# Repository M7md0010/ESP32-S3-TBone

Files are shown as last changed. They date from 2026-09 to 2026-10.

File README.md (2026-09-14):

<p align="center">
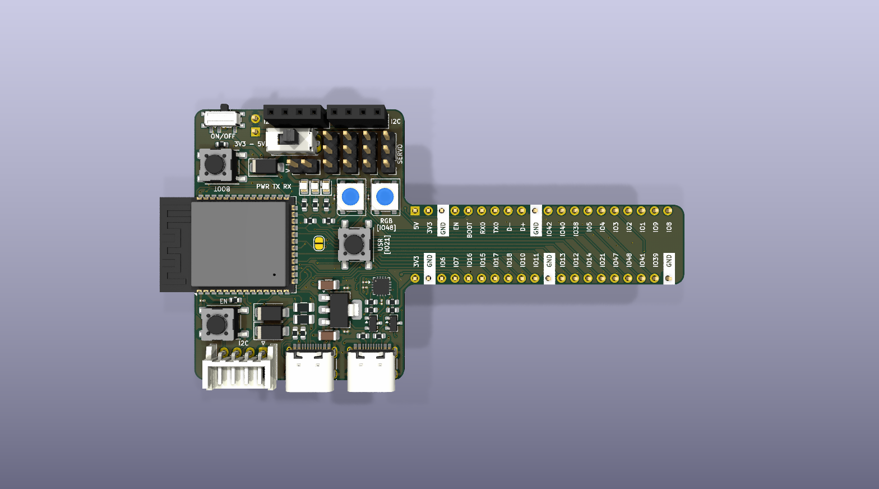
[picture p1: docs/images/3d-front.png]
ESP32-S3-TBone — Front 3D Render
  
</p>

<h1 align="center">ESP32-S3-TBone</h1>

<p align="center">
  <em>Custom T-bone form-factor ESP32-S3 development board engineered to resolve solderless breadboard real estate constraints by exposing dual-sided tie points.</em>
</p>

<p align="center">
  
  
  
  
</p>

---

## 📋 Project Overview

The **ESP32-S3-TBone** is a purpose-engineered development board built around the **ESP32-S3-WROOM-1** module. Unlike standard rectangular devkits that monopolize the entire breadboard, the T-bone form factor features a narrowed neck section that straddles the center channel while the head section extends beyond the breadboard edge — freeing up **both sides** of the breadboard for prototyping access to all GPIO tie points.

### Key Design Goals

- **Maximize breadboard usable area** — dual-sided tie point access for all broken-out GPIOs.
- **Signal integrity first** — 4-layer controlled-impedance stackup with dedicated ground and power reference planes.
- **Manufacturing ready** — Gerber-optimized output with DFM rule compliance for standard PCB fabs (JLCPCB, PCBWay, Norisolutions).
- **Mechanical validation** — 3D collision-checked against standard 830-point breadboard models in Fusion 360.

---

## 🏗️ Hardware Architecture & Stackup

### MCU: ESP32-S3-WROOM-1

| Parameter | Specification |
| --- | --- |
| Core | Xtensa® dual-core 32-bit LX7 |
| Clock | Up to 240 MHz |
| Flash | 16 MB (Quad SPI) |
| SRAM | 512 KB |
| Connectivity | Wi-Fi 802.11 b/g/n + Bluetooth 5 (LE)  |
| USB | Native USB 2.0 OTG + UART via CH343P |
| GPIO | Fully broken-out via dual header rows |

### Onboard Hardware Features & Peripherals

- **I2C Interface:** Dedicated extracted socket/pins for fast and reliable I2C peripheral expansion.
- **Servo Motor Headers:** Onboard header pins specifically broken out for direct servo motor control.
- **Addressable RGB LEDs:** 2× onboard WS2812B RGB LEDs for customizable status indication and visual feedback.
- **Flexible Power Inputs:** Power the board via either of the USB Type-C ports or directly through the header pins.
- **Switchable Breadboard Power Rails:** Two mechanically fit pins designed to drop directly into the breadboard's power rails. Features a dedicated toggle switch to select between **3.3V** and **5V** logic levels for the breadboard.
- **Main Power Switch:** Dedicated ON/OFF toggle switch for main board power.
- **Programmable User Button:** A custom tactile push button hooked up with a pull resistor, ready to be programmed for user input.
- **PTC Thermistors:** Onboard resettable fuses for robust overcurrent protection.

### 4-Layer PCB Stackup

```
┌─────────────────────────────────────────────────────────┐
│  Layer 1 — F.Cu (Top)                                   │
│  → High-density signal routing, component pads,         │
│    USB differential pairs, crystal oscillator traces     │
├─────────────────────────────────────────────────────────┤
│  Layer 2 — In1.Cu (Inner 1)                             │
│  → Solid continuous ground (GND) reference plane        │
│    Provides low-impedance return path for all signals   │
├─────────────────────────────────────────────────────────┤
│  Layer 3 — In2.Cu (Inner 2)                             │
│  → Partitioned low-impedance power planes               │
│    • 3V3 polygon pour — main logic supply               │
│    • 5V rail — USB VBUS passthrough                     │
│    • VBUS — upstream USB input power                    │
├─────────────────────────────────────────────────────────┤
│  Layer 4 — B.Cu (Bottom)                                │
│  → Bottom interconnects, ground return stitching,       │
│    thermal relief pads, and auxiliary signal routing     │
└─────────────────────────────────────────────────────────┘
```

---

## 🔧 Design For Manufacturability (DFM) & Layout

### EMI Shielding — Perimeter Via Stitching
A continuous array of stitching vias along the board perimeter connects the top and bottom ground pours, forming a **Faraday cage** effect. This:
- Contains return currents within the board stackup
- Reduces edge-radiated EMI emissions
- Improves ground plane continuity at board boundaries

### Neck Corner Geometry — CNC Routing Clearance
The interior corners at the T-bone neck-to-head transition use **chamfered/radiused fillets** to accommodate standard CNC routing bit diameters (≥ 0.8 mm). Sharp 90° interior corners are physically impossible to mill and would cause fabrication rejects.

### Soldermask-Clipped Silkscreen
The `--subtract-soldermask` flag was used during Gerber generation to automatically **clip silkscreen artwork** wherever it overlaps exposed copper pads. This prevents:
- Ink-on-pad contamination during soldering
- Poor solder wetting on component pads
- IPC-A-610 Class 2/3 violations

### USB Type-C CC Pull-Down Logic
Both USB-C ports implement the correct **CC1/CC2 pull-down resistor** network (5.1 kΩ to GND) on each Configuration Channel pin, advertising the device as a **UFP (Upstream Facing Port)** sink per USB Type-C spec Rev 2.0. This ensures reliable cable detection and power negotiation with all USB-C hosts and chargers.

---

## 🧊 Mechanical Validation

The board outline (exported as `.step` from KiCad) was imported into **Autodesk Fusion 360** alongside a reference breadboard CAD model to perform:

1. **Collision detection** — verify zero interference between the PCB body and breadboard clips/housing.
2. **Tie-point clearance** — confirm all header pins align with breadboard hole pitch (2.54 mm / 0.1").
3. **Overhang validation** — ensure the head section clears the breadboard edge without cantilever instability.

<p align="center">
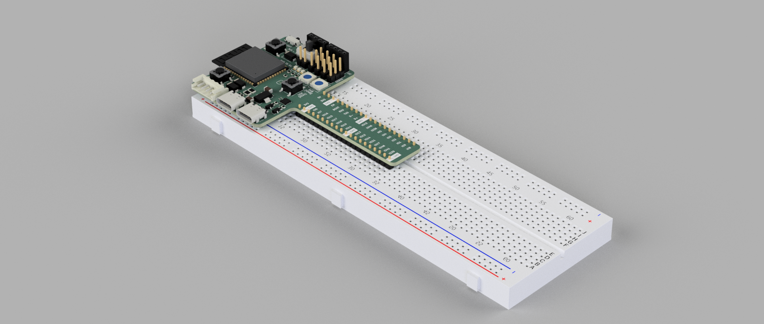
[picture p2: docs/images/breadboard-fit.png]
Breadboard fit verification
  
</p>

---

## 📸 Gallery

| Front (3D Render) | Back (3D Render) |
|---|---|
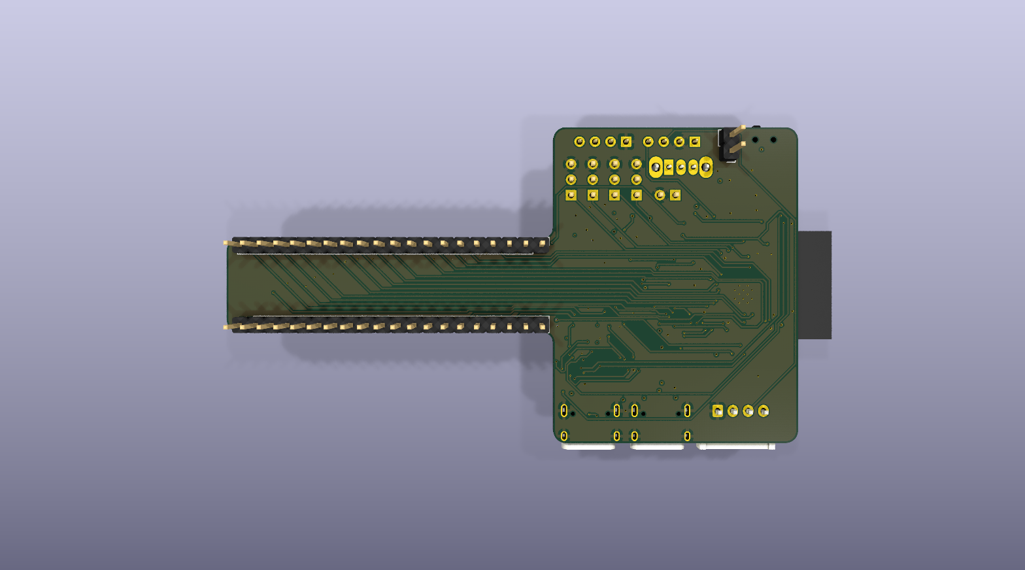
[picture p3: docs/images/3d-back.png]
Back
| Front |  |

| Front (No Components) | Back (No Components) |
|---|---|
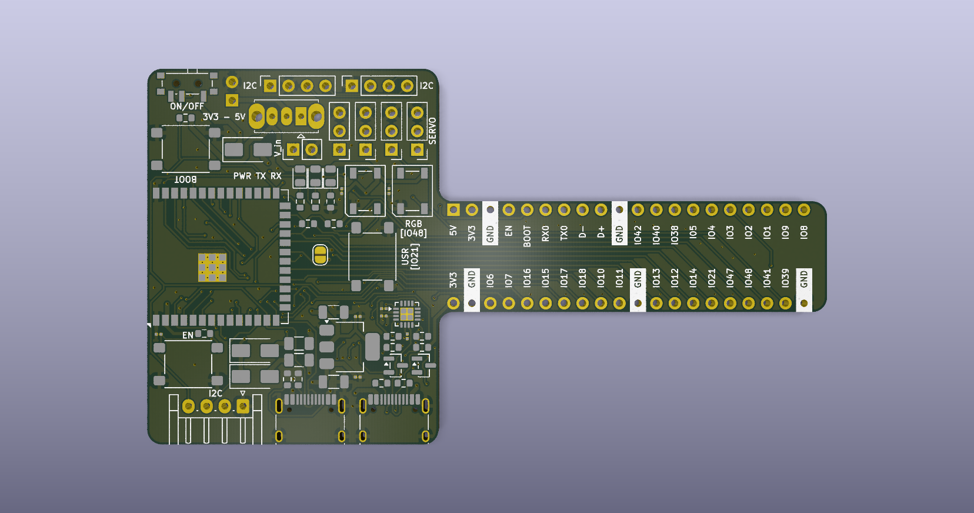
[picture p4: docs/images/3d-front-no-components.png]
Front NC
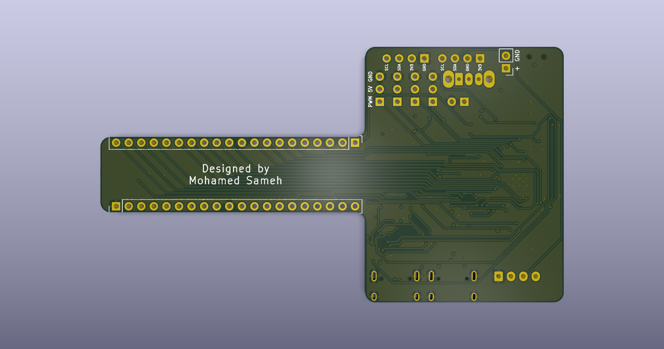
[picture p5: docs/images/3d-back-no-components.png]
Back NC
|  |  |

---

## 📁 Directory Structure

```
ESP32-S3-TBone/
├── hardware/
│   ├── schematics/
│   │   ├── schematic.pdf            # Exported schematic drawing (PDF)
│   │   └── v1.0.kicad_sch           # KiCad schematic source
│   ├── pcb/
│   │   ├── v1.0.kicad_pcb           # KiCad PCB layout source
│   │   ├── v1.0.kicad_pro           # KiCad project file
│   │   └── v1.0.kicad_dru           # KiCad design rules
│   ├── gerbers/
│   │   ├── gerbers.zip              # Production-ready Gerber + Drill archive
│   │   ├── v1.0-F_Cu.gtl            # Front copper
│   │   ├── v1.0-In1_Cu.g1           # Inner layer 1 (GND plane)
│   │   ├── v1.0-In2_Cu.g2           # Inner layer 2 (Power planes)
│   │   ├── v1.0-B_Cu.gbl            # Back copper
│   │   ├── v1.0-F_Mask.gts          # Front solder mask
│   │   ├── v1.0-B_Mask.gbs          # Back solder mask
│   │   ├── v1.0-F_Silkscreen.gto    # Front silkscreen
│   │   ├── v1.0-B_Silkscreen.gbo    # Back silkscreen
│   │   ├── v1.0-Edge_Cuts.gm1       # Board outline
│   │   ├── v1.0.drl                 # Excellon drill file
│   │   ├── v1.0-drl_map.gbr         # Drill map (Gerber X2)
│   │   └── ...                      # Additional fabrication layers
│   └── mechanical/
│       ├── ESP32-S3-TBone.step       # 3D STEP assembly export
│       ├── Breadboard.fbx            # Breadboard reference model
│       └── breadboard-reference.glb  # Breadboard GLB model
├── docs/
│   └── images/
│       ├── 3d-front.png              # Front 3D render
│       ├── 3d-back.png               # Back 3D render
│       ├── 3d-front-no-components.png
│       ├── 3d-back-no-components.png
│       ├── breadboard-fit.png        # Breadboard fit verification
│       └── comparison.png            # Size comparison
├── .gitignore
├── LICENSE                            # MIT License
└── README.md                          # This file
```

---

## 🛠️ Regenerating Manufacturing Files

If you modify the KiCad source files, regenerate all outputs using `kicad-cli`:

```bash
# Gerber layers (with soldermask-clipped silkscreen)
kicad-cli pcb export gerbers --subtract-soldermask \
  -o hardware/gerbers/ hardware/pcb/v1.0.kicad_pcb

# Excellon drill files + Gerber X2 drill map
kicad-cli pcb export drill --generate-map --map-format gerberx2 \
  -o hardware/gerbers/ hardware/pcb/v1.0.kicad_pcb

# Schematic PDF
kicad-cli sch export pdf \
  -o hardware/schematics/schematic.pdf hardware/schematics/v1.0.kicad_sch

# STEP 3D assembly (skip DNP, substitute models)
kicad-cli pcb export step --no-dnp --subst-models \
  -o hardware/mechanical/ESP32-S3-TBone.step hardware/pcb/v1.0.kicad_pcb
```

---

## 📜 License

This project is licensed under the **MIT License** — see the [LICENSE](./LICENSE) file for details.

---

<p align="center">
  <sub>Designed & engineered by <a href="https://github.com/M7md0010">@M7md0010</a></sub>
</p>

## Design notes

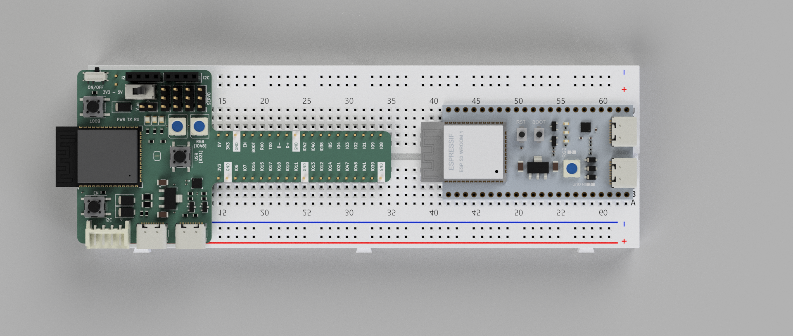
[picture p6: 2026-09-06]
docs/images/comparison.png

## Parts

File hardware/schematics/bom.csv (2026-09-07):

Refs | Value | Footprint | Qty | DNP
C1 | 100 nF | Capacitor_SMD:C_0201_0603Metric | 1
C2 | 100 nF | Capacitor_SMD:C_0201_0603Metric | 1
C3 | 100 nF | Capacitor_SMD:C_0201_0603Metric | 1
C4 | 100 nF | Capacitor_SMD:C_0201_0603Metric | 1
C5 | 100 nF | Capacitor_SMD:C_0201_0603Metric | 1
C6 | 100 nF | Capacitor_SMD:C_0201_0603Metric | 1
C7 | 22μF | Capacitor_SMD:C_1206_3216Metric | 1
C8 | 100nF | Capacitor_SMD:C_0201_0603Metric | 1
C9 | 100nF | Capacitor_SMD:C_0201_0603Metric | 1
C10 | 22μF | Capacitor_SMD:C_1206_3216Metric | 1
D1 | SS34 | Diode_SMD:D_SMA | 1
D2 | SS34 | Diode_SMD:D_SMA | 1
D3 | SS34 | Diode_SMD:D_SMA | 1
D6 | LED | LED_SMD:LED_0805_2012Metric | 1
D7 | LED | LED_SMD:LED_0805_2012Metric | 1
D8 | LED | LED_SMD:LED_0805_2012Metric | 1
D9 | WS2812B | LED_SMD:LED_WS2812B_PLCC4_5.0x5.0mm_P3.2mm | 1
D10 | WS2812B | LED_SMD:LED_WS2812B_PLCC4_5.0x5.0mm_P3.2mm | 1
J1 | Conn_01x04_Pin | Connector_PinSocket_2.54mm:PinSocket_1x04_P2.54mm_Vertical | 1
J2 | Conn_01x04_Pin | Connector_PinSocket_2.54mm:PinSocket_1x04_P2.54mm_Vertical | 1
J3 | Conn_01x03_Pin | Connector_PinHeader_2.54mm:PinHeader_1x03_P2.54mm_Vertical | 1
J4 | Conn_01x03_Pin | Connector_PinHeader_2.54mm:PinHeader_1x03_P2.54mm_Vertical | 1
J5 | Conn_01x03_Pin | Connector_PinHeader_2.54mm:PinHeader_1x03_P2.54mm_Vertical | 1
J6 | Conn_01x03_Pin | Connector_PinHeader_2.54mm:PinHeader_1x03_P2.54mm_Vertical | 1
J7 | USB_C_Receptacle_USB2.0_14P | Connector_USB:USB_C_Receptacle_HRO_TYPE-C-31-M-12 | 1
J8 | Conn_01x20_Pin | Connector_PinHeader_2.54mm:PinHeader_1x20_P2.54mm_Vertical | 1
J9 | Conn_01x20_Pin | Connector_PinHeader_2.54mm:PinHeader_1x20_P2.54mm_Vertical | 1
J10 | Conn_01x04_Socket | Connector_JST:JST_EH_S4B-EH_1x04_P2.50mm_Horizontal | 1
J11 | USB_C_Receptacle_USB2.0_14P | Connector_USB:USB_C_Receptacle_HRO_TYPE-C-31-M-12 | 1
J14 | Conn_01x02_Pin | Connector_PinHeader_2.54mm:PinHeader_1x02_P2.54mm_Vertical | 1
J15 | Conn_01x02_Pin | Connector_PinHeader_2.54mm:PinHeader_1x02_P2.54mm_Vertical | 1
JP2 | Jumper_2_Open | Jumper:SolderJumper-2_P1.3mm_Open_RoundedPad1.0x1.5mm | 1
Q1 | MMBT3904 | Package_TO_SOT_SMD:SOT-23 | 1
Q2 | MMBT3904 | Package_TO_SOT_SMD:SOT-23 | 1
R1 | 5.1kΩ | Resistor_SMD:R_0603_1608Metric | 1
R2 | 5.1kΩ | Resistor_SMD:R_0603_1608Metric | 1
R3 | 10kΩ | Resistor_SMD:R_0603_1608Metric | 1
R4 | 10kΩ | Resistor_SMD:R_0603_1608Metric | 1
R5 | 10kΩ | Resistor_SMD:R_0603_1608Metric | 1
R6 | 5.1kΩ | Resistor_SMD:R_0603_1608Metric | 1
R7 | 5.1kΩ | Resistor_SMD:R_0603_1608Metric | 1
R8 | 10kΩ | Resistor_SMD:R_0603_1608Metric | 1
R9 | 10kΩ | Resistor_SMD:R_0603_1608Metric | 1
R10 | 10kΩ | Resistor_SMD:R_0603_1608Metric | 1
R11 | 10kΩ | Resistor_SMD:R_0603_1608Metric | 1
R12 | 330Ω | Resistor_SMD:R_0603_1608Metric | 1
R13 | 1kΩ | Resistor_SMD:R_0603_1608Metric | 1
R14 | 1kΩ | Resistor_SMD:R_0603_1608Metric | 1
R15 | 1kΩ | Resistor_SMD:R_0603_1608Metric | 1
SW1 | SW_Push | Button_Switch_SMD:SW_SPST_PTS645Sx43SMTR92 | 1
SW2 | SW_Push | Button_Switch_SMD:SW_SPST_PTS645Sx43SMTR92 | 1
SW3 | SW_Push | Button_Switch_SMD:SW_SPST_PTS645Sx43SMTR92 | 1
SW4 | SW_SPDT | Button_Switch_SMD:SW_SPDT_PCM12 | 1
SW5 | SW_SPDT | Button_Switch_THT:SW_Slide_SPDT_Straight_CK_OS102011MS2Q | 1
TH1 | Thermistor_PTC | Fuse:Fuse_1206_3216Metric | 1
TH2 | Thermistor_PTC | Fuse:Fuse_1206_3216Metric | 1
U1 | CH343P | Package_DFN_QFN:WCH_QFN-16-1EP_3x3mm_P0.5mm_EP1.8x1.8mm | 1
U2 | ESP32-S3-WROOM-1 | RF_Module:ESP32-S3-WROOM-1 | 1
U3 | AMS1117-3.3 | Package_TO_SOT_SMD:SOT-223-3_TabPin2 | 1

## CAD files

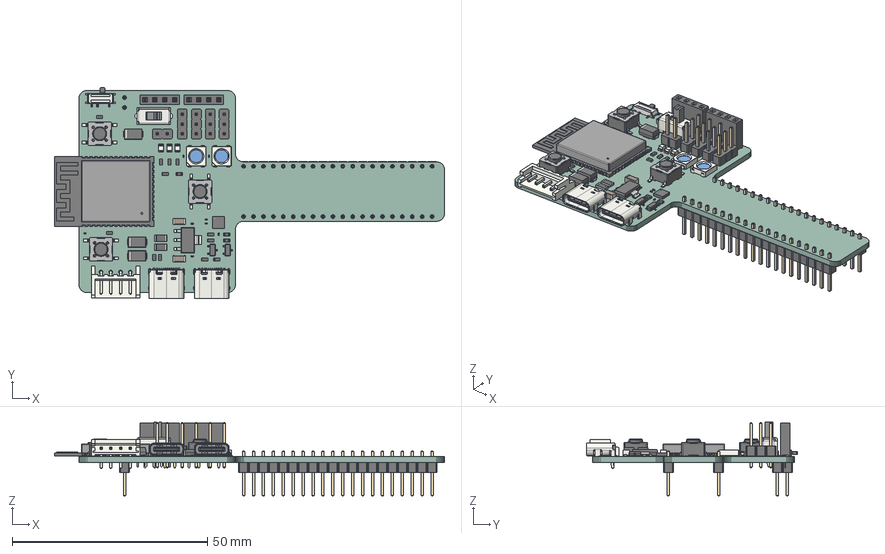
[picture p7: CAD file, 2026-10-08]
hardware/mechanical/v1.0.step
99.8 x 54.0 x 18.9 mm
R_0603_1608Metric x 15
Fusion_sp
LED_WS2812B_PLCC4_50x50mm_P32mm x 2
C_0201_0603Metric x 8
LED_0805_2012Metric x 3
SW_Slide_SPDT_Straight_CK_OS102011MS2Q
SW_SPST_PTS645Sx43SMTR92 x 3
USB_C_Receptacle_16P_TopMnt_Horizontal_GCT_USB4105-xx-A x 2
PinHeader_1x02_P254mm_Vertical x 2
PinHeader_1x03_P254mm_Vertical x 4
SOT-223
D_SMA x 3
SOT-23 x 2
QFN-16-1EP_3x3mm_P0.5mm_EP1.7x1.7mm
C_1206_3216Metric x 2
PinSocket_1x04_P2.54mm_Vertical x 2
JST_S4B_EH
Fuse_1206_3216Metric x 2
ESP32-S3-WROOM-1
PinHeader_1x20_P254mm_Vertical x 2
v1.0_PCB

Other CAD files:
hardware/mechanical/ESP32-S3-TBone.step

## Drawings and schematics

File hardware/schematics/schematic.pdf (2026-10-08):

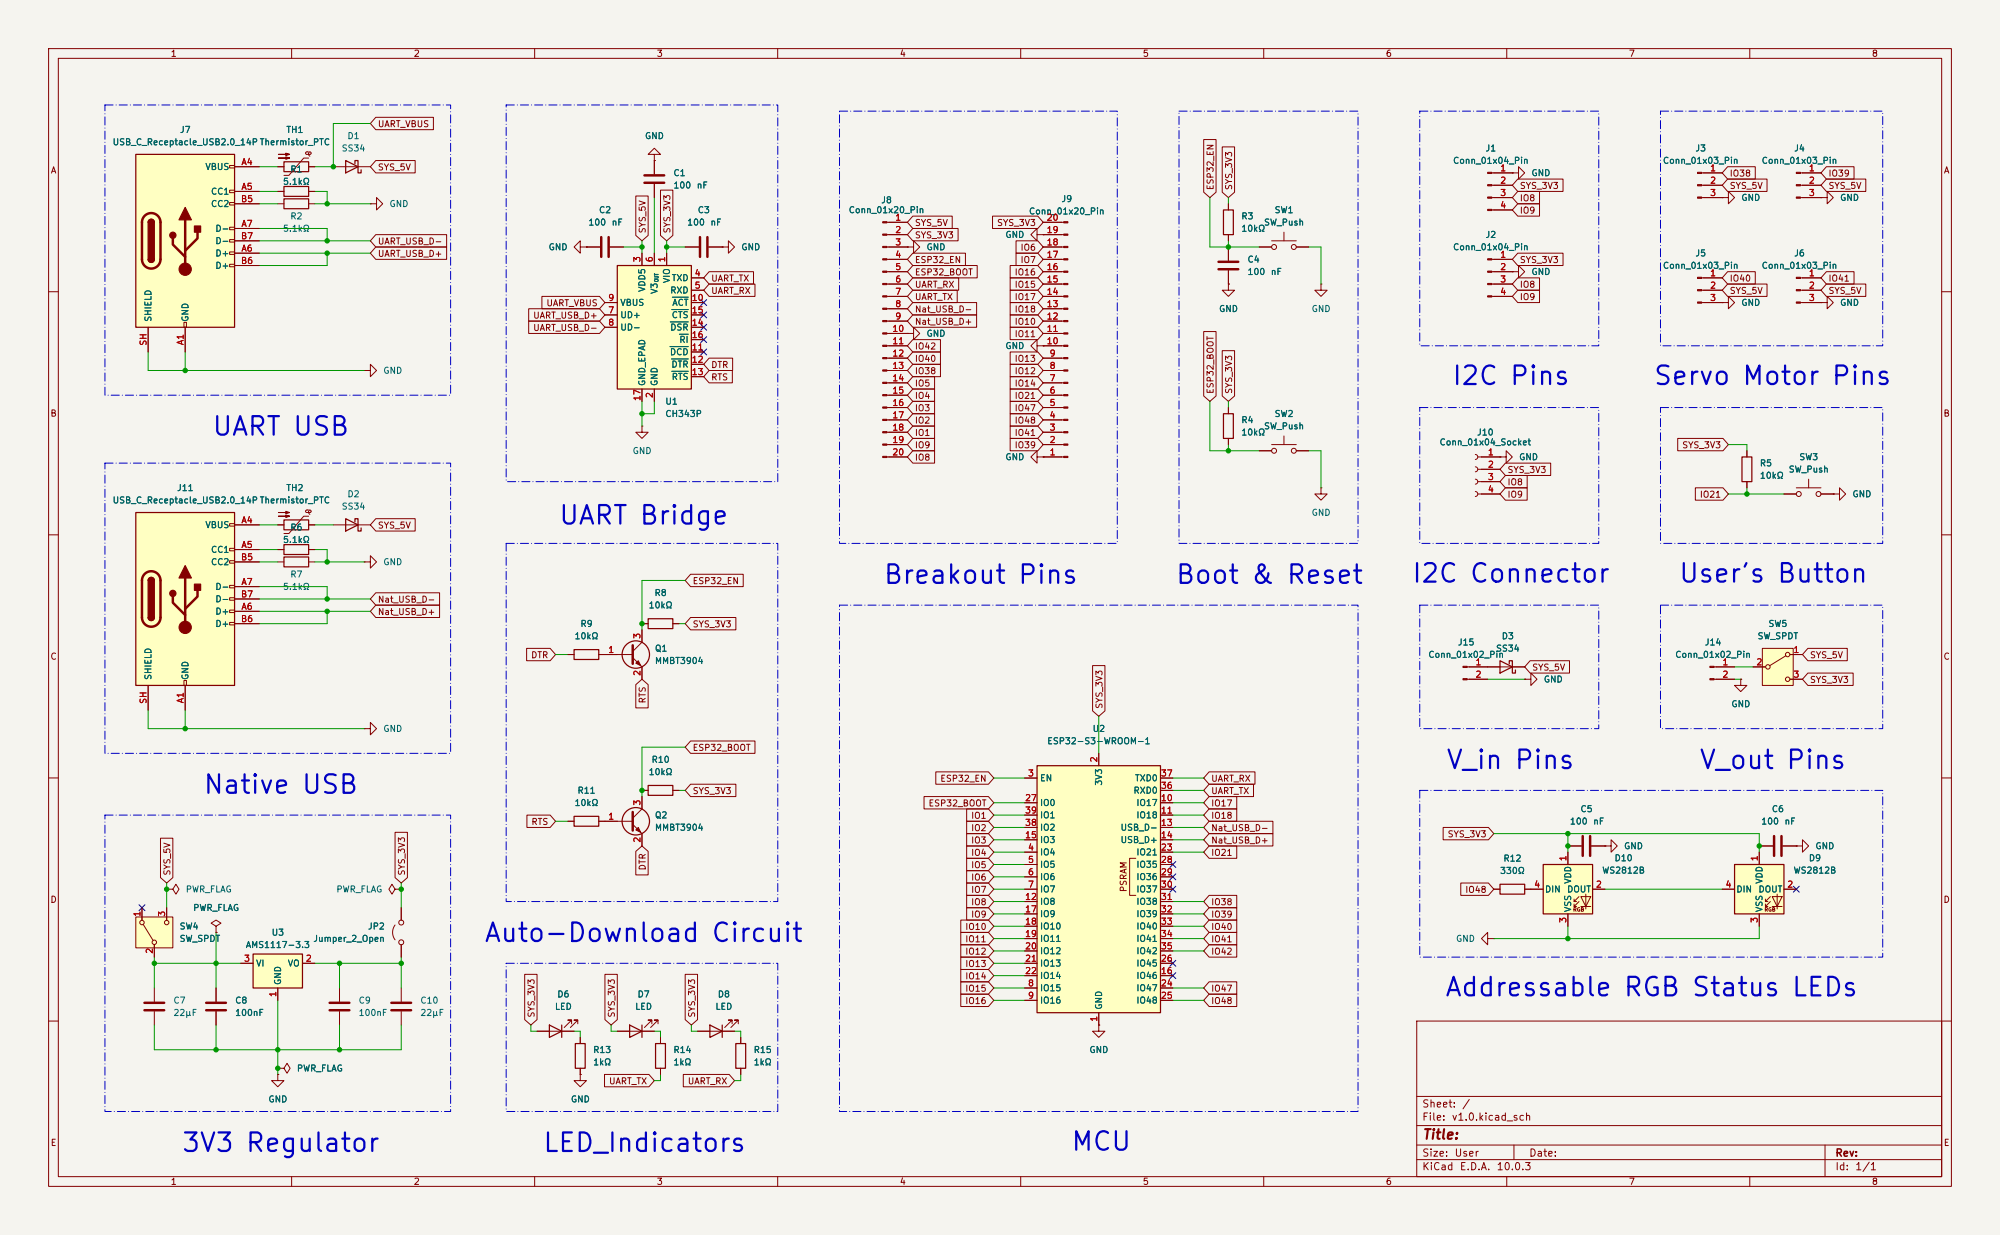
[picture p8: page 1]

ACT 10 DCD 11 DTR 12 RTS 13 DSR 14 CTS 15 RI 16 C2

1 VDD5
ACT 10 DCD 11 DTR 12 RTS 13 DSR 14 CTS 15 RI 16 U1CH343P

GND
Addressable RGB Status LEDs

Size: User | Rev:
KiCad E.D.A. 10.0.3 | Id: 1/1

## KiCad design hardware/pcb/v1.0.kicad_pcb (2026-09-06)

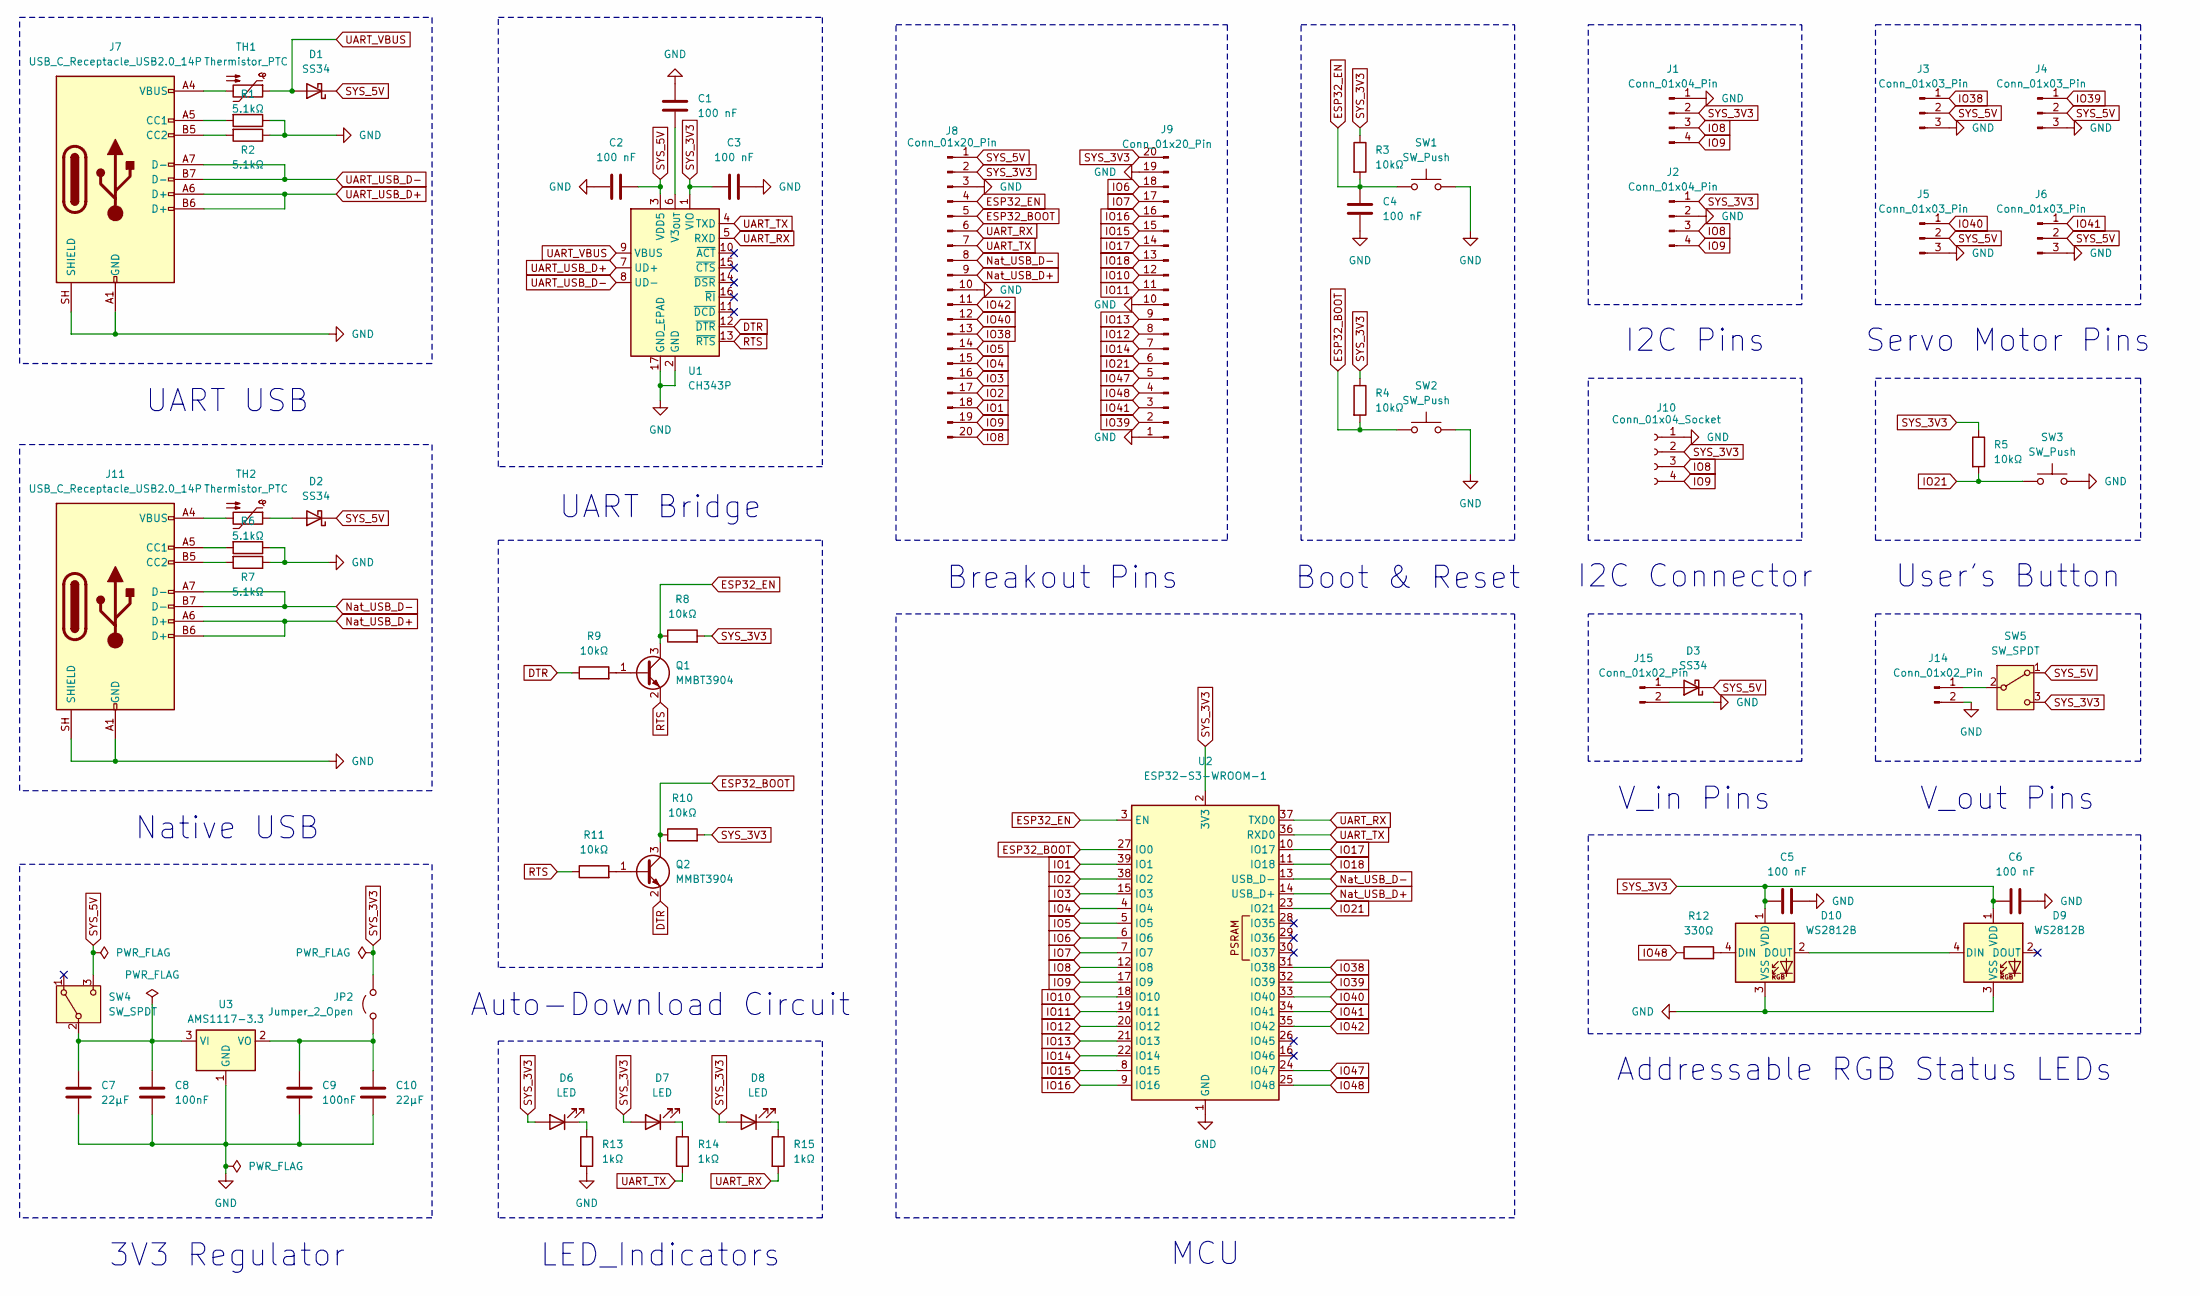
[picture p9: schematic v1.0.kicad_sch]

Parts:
C1, C2, C3, C4, C5, C6: 100 nF; C_0201_0603Metric
C7, C10: 22μF; C_1206_3216Metric
C8, C9: 100nF; C_0201_0603Metric
D1, D2, D3: SS34; D_SMA
D6, D7, D8: LED; LED_0805_2012Metric
D9, D10: WS2812B; LED_WS2812B_PLCC4_5.0x5.0mm_P3.2mm
J1, J2: Conn_01x04_Pin; PinSocket_1x04_P2.54mm_Vertical
J3, J4, J5, J6: Conn_01x03_Pin; PinHeader_1x03_P2.54mm_Vertical
J7, J11: USB_C_Receptacle_USB2.0_14P; USB_C_Receptacle_HRO_TYPE-C-31-M-12
J8, J9: Conn_01x20_Pin; PinHeader_1x20_P2.54mm_Vertical
J10: Conn_01x04_Socket; JST_EH_S4B-EH_1x04_P2.50mm_Horizontal
J14, J15: Conn_01x02_Pin; PinHeader_1x02_P2.54mm_Vertical
JP2: Jumper_2_Open; SolderJumper-2_P1.3mm_Open_RoundedPad1.0x1.5mm
Q1, Q2: MMBT3904; SOT-23
R1, R2, R6, R7: 5.1kΩ; R_0603_1608Metric
R3, R4, R5, R8, R9, R10, R11: 10kΩ; R_0603_1608Metric
R12: 330Ω; R_0603_1608Metric
R13, R14, R15: 1kΩ; R_0603_1608Metric
SW1, SW2, SW3: SW_Push; SW_SPST_PTS645Sx43SMTR92
SW4: SW_SPDT; SW_SPDT_PCM12
SW5: SW_SPDT; SW_Slide_SPDT_Straight_CK_OS102011MS2Q
TH1, TH2: Thermistor_PTC; Fuse_1206_3216Metric
U1: CH343P; WCH_QFN-16-1EP_3x3mm_P0.5mm_EP1.8x1.8mm
U2: ESP32-S3-WROOM-1
U3: AMS1117-3.3; SOT-223-3_TabPin2

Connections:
DTR: Q2.2 (E), R9.1, U1.12 (~DTR)
ESP32_BOOT: J8.5, Q2.3 (C), R4.2, R10.1, SW2.1, U2.27 (IO0)
ESP32_EN: C4.1, J8.4, Q1.3 (C), R3.2, R8.1, SW1.1, U2.3 (EN)
GND: C1.1, C2.2, C3.1, C4.2, C5.1, C6.1, C7.2, C8.2, C9.2, C10.2, D9.3 (VSS), D10.3 (VSS), J1.1, J2.2, J3.3, J4.3, J5.3, J6.3, J7.A1 (GND), J7.A12 (GND), J7.B1 (GND), J7.B12 (GND), J7.SH (SHIELD), J8.3, J8.10, J9.1, J9.10, J9.19, J10.1, J11.A1 (GND), J11.A12 (GND), J11.B1 (GND), J11.B12 (GND), J11.SH (SHIELD), J14.2, J15.2, R1.1, R2.1, R6.1, R7.1, R13.2, SW1.2, SW2.2, SW3.2, U1.2 (GND), U1.17 (GND_EPAD), U2.1 (GND), U2.40 (GND), U2.41 (GND), U3.1 (GND)
IO1: J8.18, U2.39 (IO1)
IO2: J8.17, U2.38 (IO2)
IO3: J8.16, U2.15 (IO3)
IO4: J8.15, U2.4 (IO4)
IO5: J8.14, U2.5 (IO5)
IO6: J9.18, U2.6 (IO6)
IO7: J9.17, U2.7 (IO7)
IO8: J1.3, J2.3, J8.20, J10.3, U2.12 (IO8)
IO9: J1.4, J2.4, J8.19, J10.4, U2.17 (IO9)
IO10: J9.12, U2.18 (IO10)
IO11: J9.11, U2.19 (IO11)
IO12: J9.8, U2.20 (IO12)
IO13: J9.9, U2.21 (IO13)
IO14: J9.7, U2.22 (IO14)
IO15: J9.15, U2.8 (IO15)
IO16: J9.16, U2.9 (IO16)
IO17: J9.14, U2.10 (IO17)
IO18: J9.13, U2.11 (IO18)
IO21: J9.6, R5.2, SW3.1, U2.23 (IO21)
IO38: J3.1, J8.13, U2.31 (IO38)
IO39: J4.1, J9.2, U2.32 (IO39)
IO40: J5.1, J8.12, U2.33 (IO40)
IO41: J6.1, J9.3, U2.34 (IO41)
IO42: J8.11, U2.35 (IO42)
IO47: J9.5, U2.24 (IO47)
IO48: J9.4, R12.1, U2.25 (IO48)
Nat_USB_D+: J8.9, J11.A6 (D+), J11.B6 (D+), U2.14 (USB_D+)
Nat_USB_D-: J8.8, J11.A7 (D-), J11.B7 (D-), U2.13 (USB_D-)
unnamed: D2.2 (A), TH2.1
unnamed: D3.2 (A), J15.1
unnamed: D6.1 (K), R13.1
unnamed: D7.1 (K), R14.1
unnamed: D8.1 (K), R15.1
unnamed: D10.4 (DIN), R12.2
unnamed: D9.4 (DIN), D10.2 (DOUT)
unnamed: J7.A5 (CC1), R1.2
unnamed: J7.B5 (CC2), R2.2
unnamed: J7.A4 (VBUS), J7.A9 (VBUS), J7.B4 (VBUS), J7.B9 (VBUS), TH1.2
unnamed: J11.A5 (CC1), R6.2
unnamed: J11.B5 (CC2), R7.2
unnamed: J11.A4 (VBUS), J11.A9 (VBUS), J11.B4 (VBUS), J11.B9 (VBUS), TH2.2
unnamed: J14.1, SW5.2 (B)
unnamed: C9.1, C10.1, JP2.1 (A), U3.2 (VO)
unnamed: Q1.1 (B), R9.2
unnamed: Q2.1 (B), R11.2
unnamed: C7.1, C8.1, SW4.2 (B), U3.3 (VI)
unnamed: C1.2, U1.6 (V3_{OUT})
RTS: Q1.2 (E), R11.1, U1.13 (~RTS)
SYS_3V3: C3.2, C5.2, C6.2, D6.2 (A), D7.2 (A), D8.2 (A), D9.1 (VDD), D10.1 (VDD), J1.2, J2.1, J8.2, J9.20, J10.2, JP2.2 (B), R3.1, R4.1, R5.1, R8.2, R10.2, SW5.3 (C), U1.1 (VIO), U2.2 (3V3)
SYS_5V: C2.1, D1.1 (K), D2.1 (K), D3.1 (K), J3.2, J4.2, J5.2, J6.2, J8.1, SW4.3 (C), SW5.1 (A), U1.3 (VDD5)
UART_RX: J8.6, R15.2, U1.5 (RXD), U2.37 (TXD0)
UART_TX: J8.7, R14.2, U1.4 (TXD), U2.36 (RXD0)
UART_USB_D+: J7.A6 (D+), J7.B6 (D+), U1.7 (UD+)
UART_USB_D-: J7.A7 (D-), J7.B7 (D-), U1.8 (UD-)
UART_VBUS: D1.2 (A), TH1.1, U1.9 (VBUS)

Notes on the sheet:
Servo Motor Pins
Auto-Download Circuit
UART USB
MCU
LED_Indicators
3V3 Regulator
Boot & Reset
Breakout Pins
UART Bridge
Native USB
User's Button
I2C Connector
V_in Pins
I2C Pins
Addressable RGB Status LEDs
V_out Pins

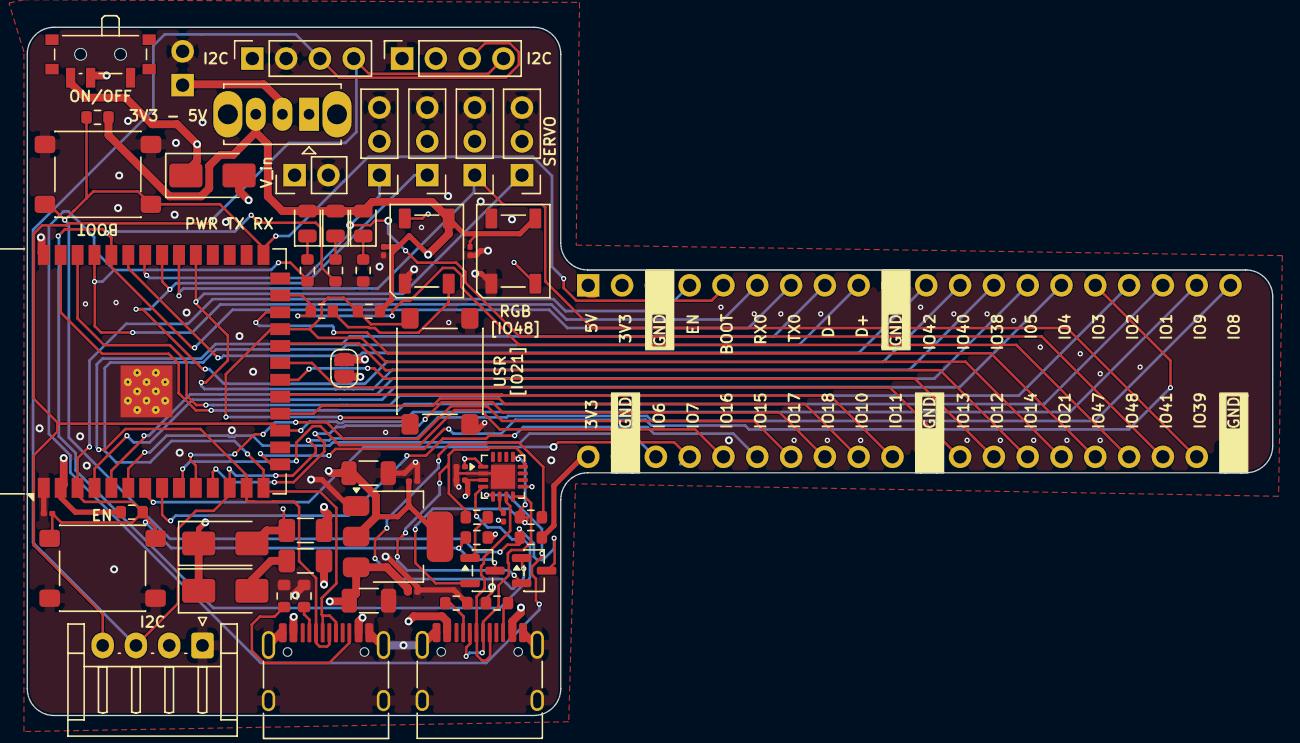
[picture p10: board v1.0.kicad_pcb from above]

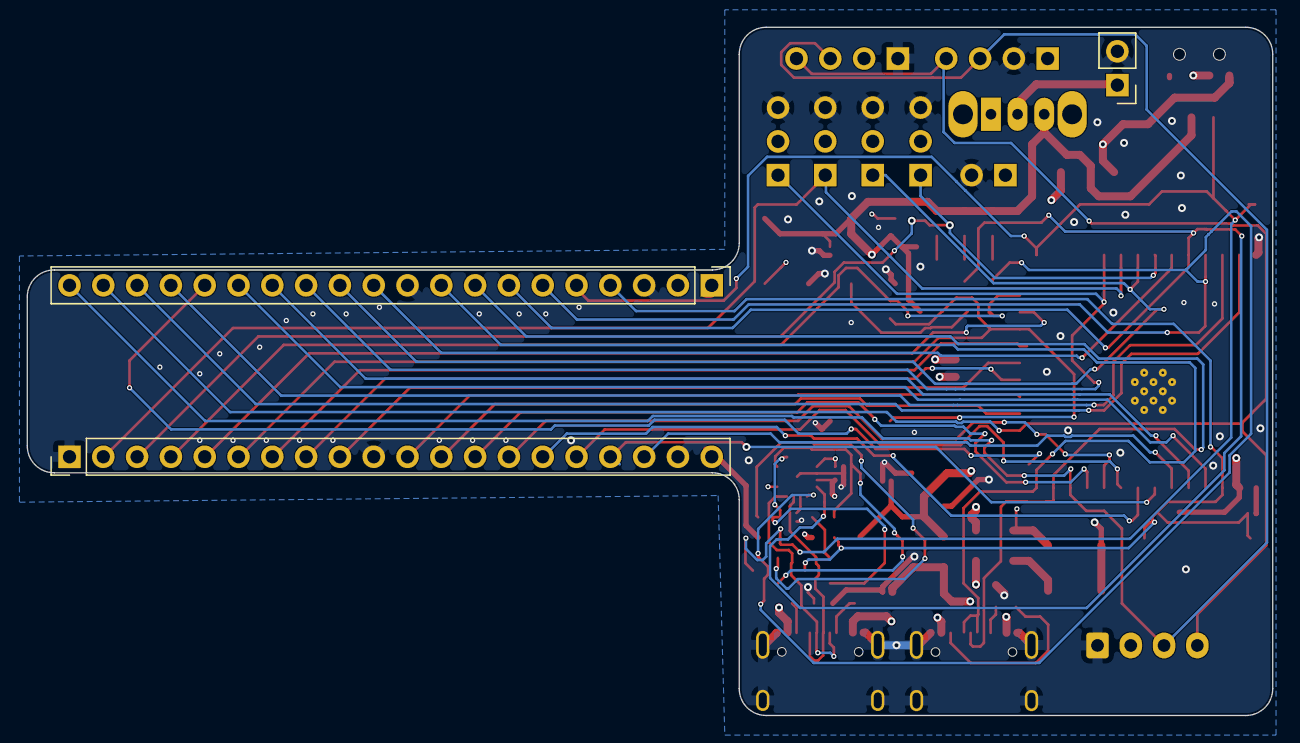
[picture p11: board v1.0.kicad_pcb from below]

Board: 4 copper layers, 93.6 x 51.7 mm, 59 parts (3 on the bottom side), 59 nets.

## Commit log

2026-09-06 feat: initial commit of ESP32-S3-TBone hardware repo
    [ESP32-S3-TBone.step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]
2026-09-06 fix: update gerbers and project files after silkscreen adjustments
    [ESP32-S3-TBone.step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]
2026-09-06 Update PCB fab list in README
    Added norisolutions
2026-09-07 Export updated KiCad fabrication files and schematic
    [bom.csv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]
2026-09-14 Update 3D render images from KiCad CLI re-export
2026-09-14 Re-export all fabrication files via KiCad 10 CLI
    - Gerbers: switched from Protel to KiCad (.gbr) extensions
    - Drill files: regenerated with gerber drill map
    - STEP: re-exported 3D model
    - Schematic PDF: re-exported
    - BOM & netlist: re-exported
    - 3D renders: regenerated front/back with high quality raytracing
    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
    [v1.0-B_Adhesive.gbr, v1.0-B_Cu.gbl, v1.0-B_Cu.gbr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]
2026-10-08 Re-export all fabrication files via KiCad 10 CLI
    [v1.0-B_Adhesive.gbr, v1.0-B_Cu.gbr, v1.0-B_Mask.gbr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]

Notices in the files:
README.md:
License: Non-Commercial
